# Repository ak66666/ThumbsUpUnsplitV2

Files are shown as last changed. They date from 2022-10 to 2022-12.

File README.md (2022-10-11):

# ThumbsUpUnsplitV2
Multilevel 44 Key Ergonomic Keyboard.
V2 puts the fourth row one level up.

The board uses Kailh Choc hot-swap switches.

//TODO Pictures to be replaced.

Main view
Three levels are visible






# Firmware
                                                               
The board uses Planck rev4 software with one pin replaced - it is needed for Cirque trackpad.
To make it work - modify \qmk_firmware\keyboards\planck\config.h, replace the pin definition with this one:

#define MATRIX_COL_PINS { D7, B4, D6, D4, F7, F6, F5, F4, C7, B0, F0, F1 }

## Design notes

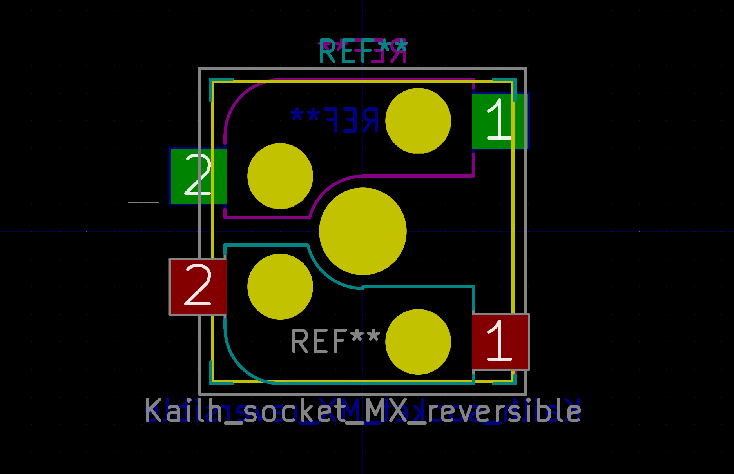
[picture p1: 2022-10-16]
keyswitches.pretty-master/images/Kailh_socket_MX_reversible_platemount.png

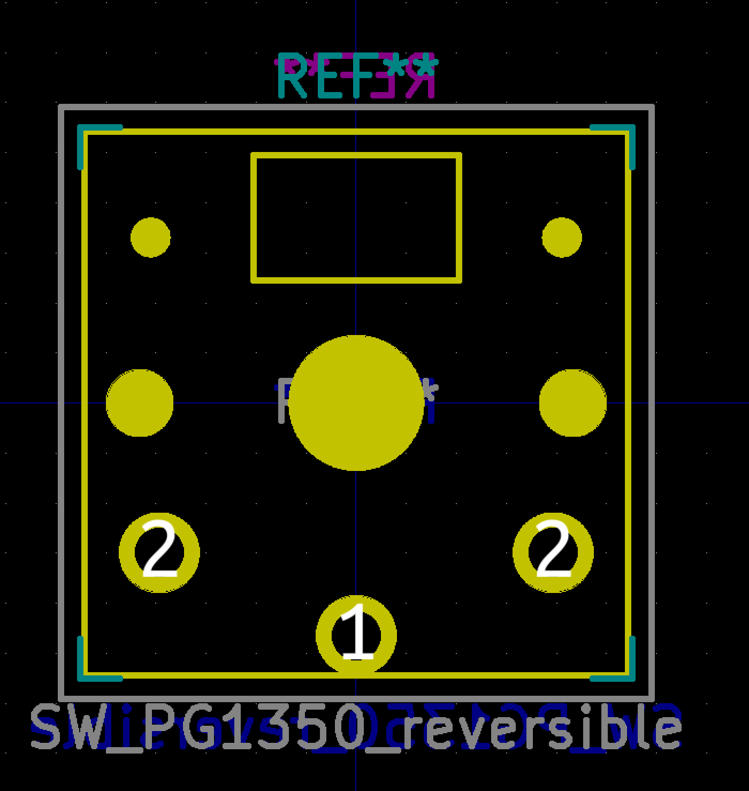
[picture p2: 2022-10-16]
keyswitches.pretty-master/images/SW_PG1350_reversible.png

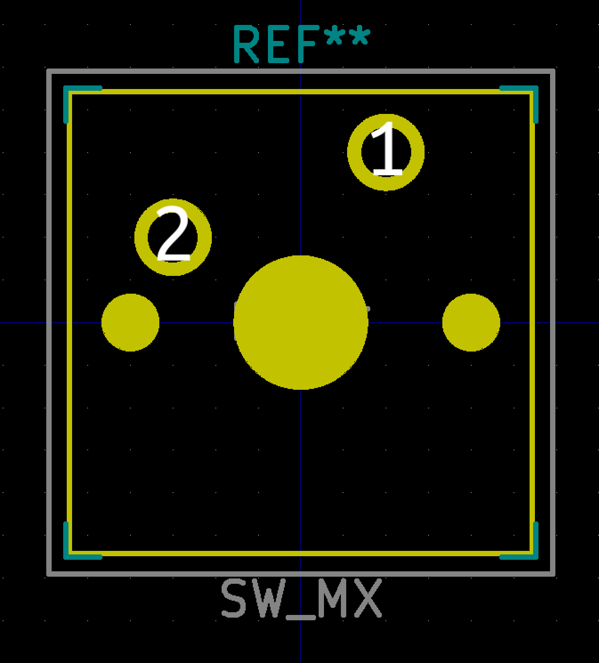
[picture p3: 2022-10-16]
keyswitches.pretty-master/images/SW_MX.png

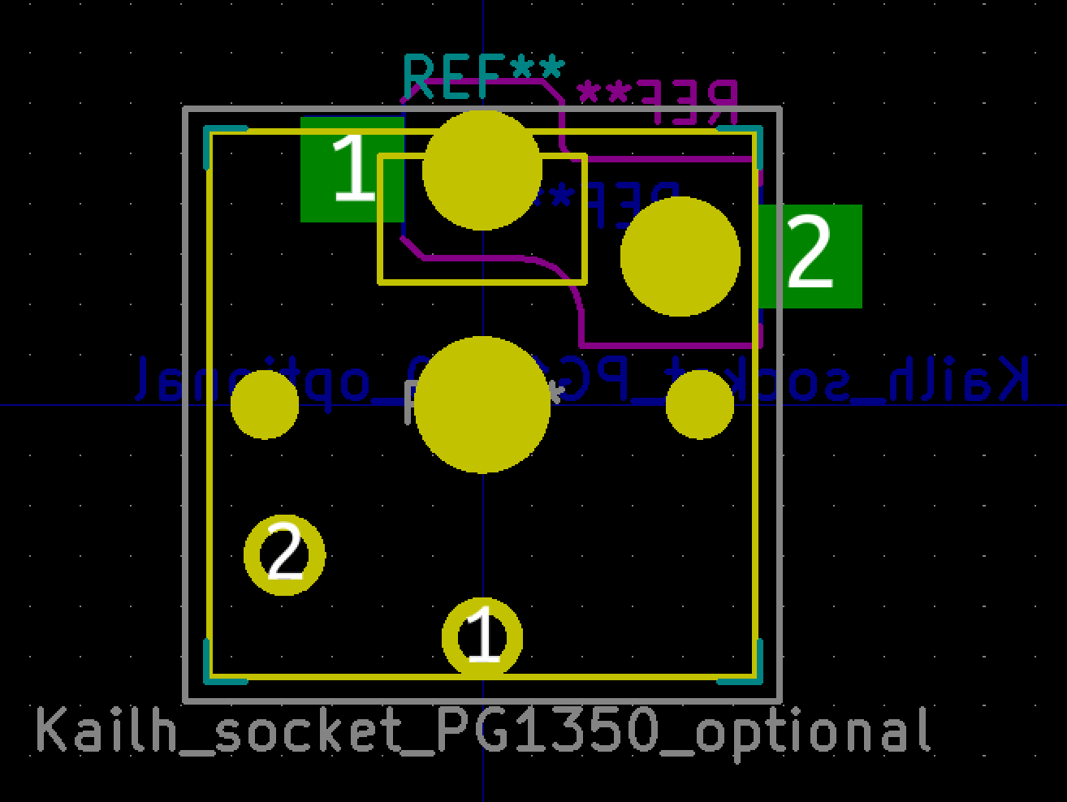
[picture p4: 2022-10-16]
keyswitches.pretty-master/images/Kailh_socket_PG1350_optional.png

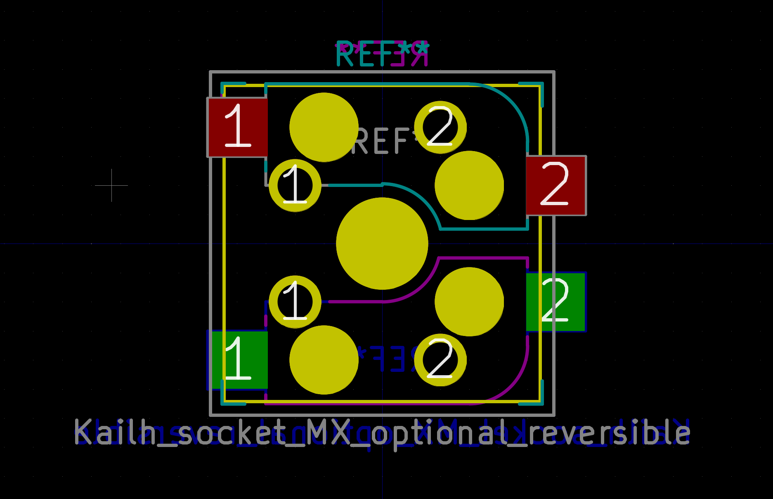
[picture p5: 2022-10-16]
keyswitches.pretty-master/images/Kailh_socket_MX_optional_reversible_platemount.png

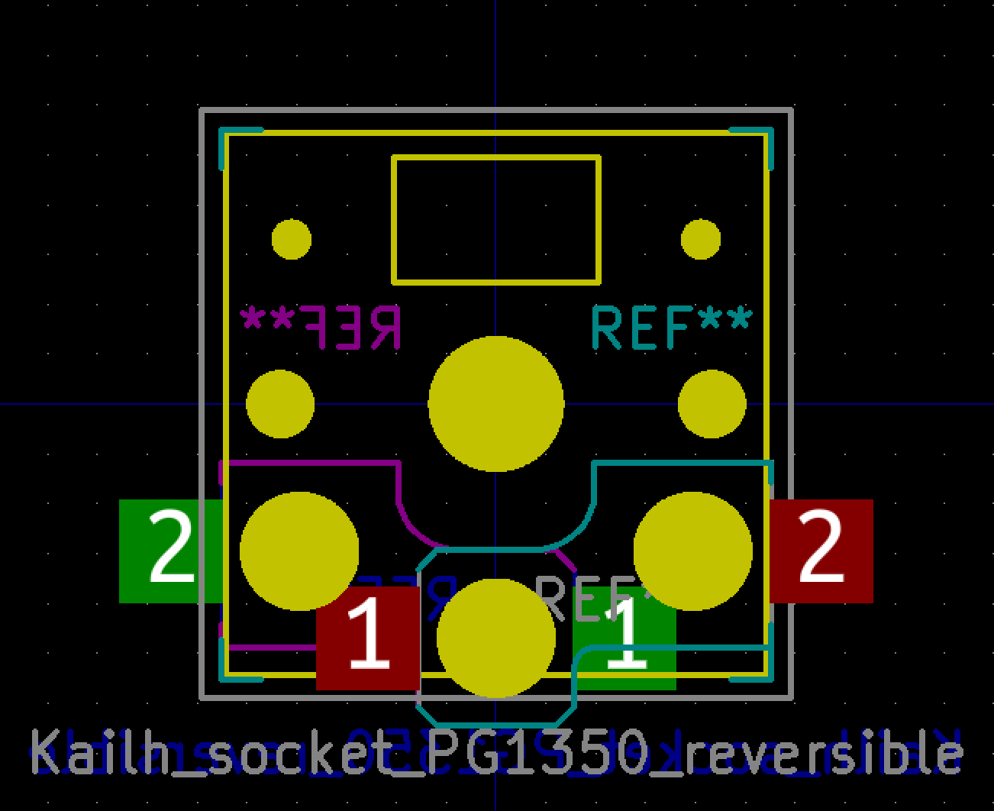
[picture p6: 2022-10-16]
keyswitches.pretty-master/images/Kailh_socket_PG1350_reversible.png

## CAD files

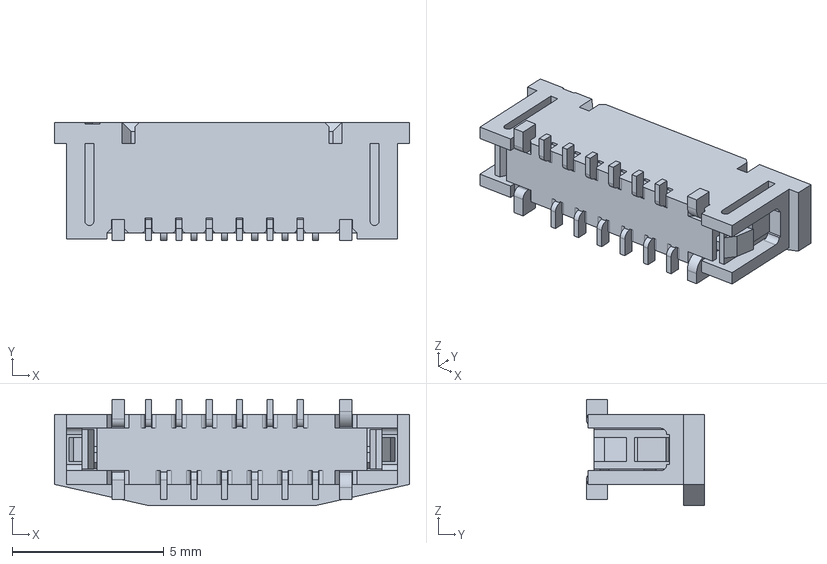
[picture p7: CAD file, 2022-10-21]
Molex 52559-1233/52559-1233/3D/52559-1233.stp
11.7 x 3.90 x 3.50 mm

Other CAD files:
Molex 52559-1233/52559-1233/Allegro/525591233.psm
Molex 52559-1233/52559-1233/DEHDL/52559_1233/chips/chips.prt

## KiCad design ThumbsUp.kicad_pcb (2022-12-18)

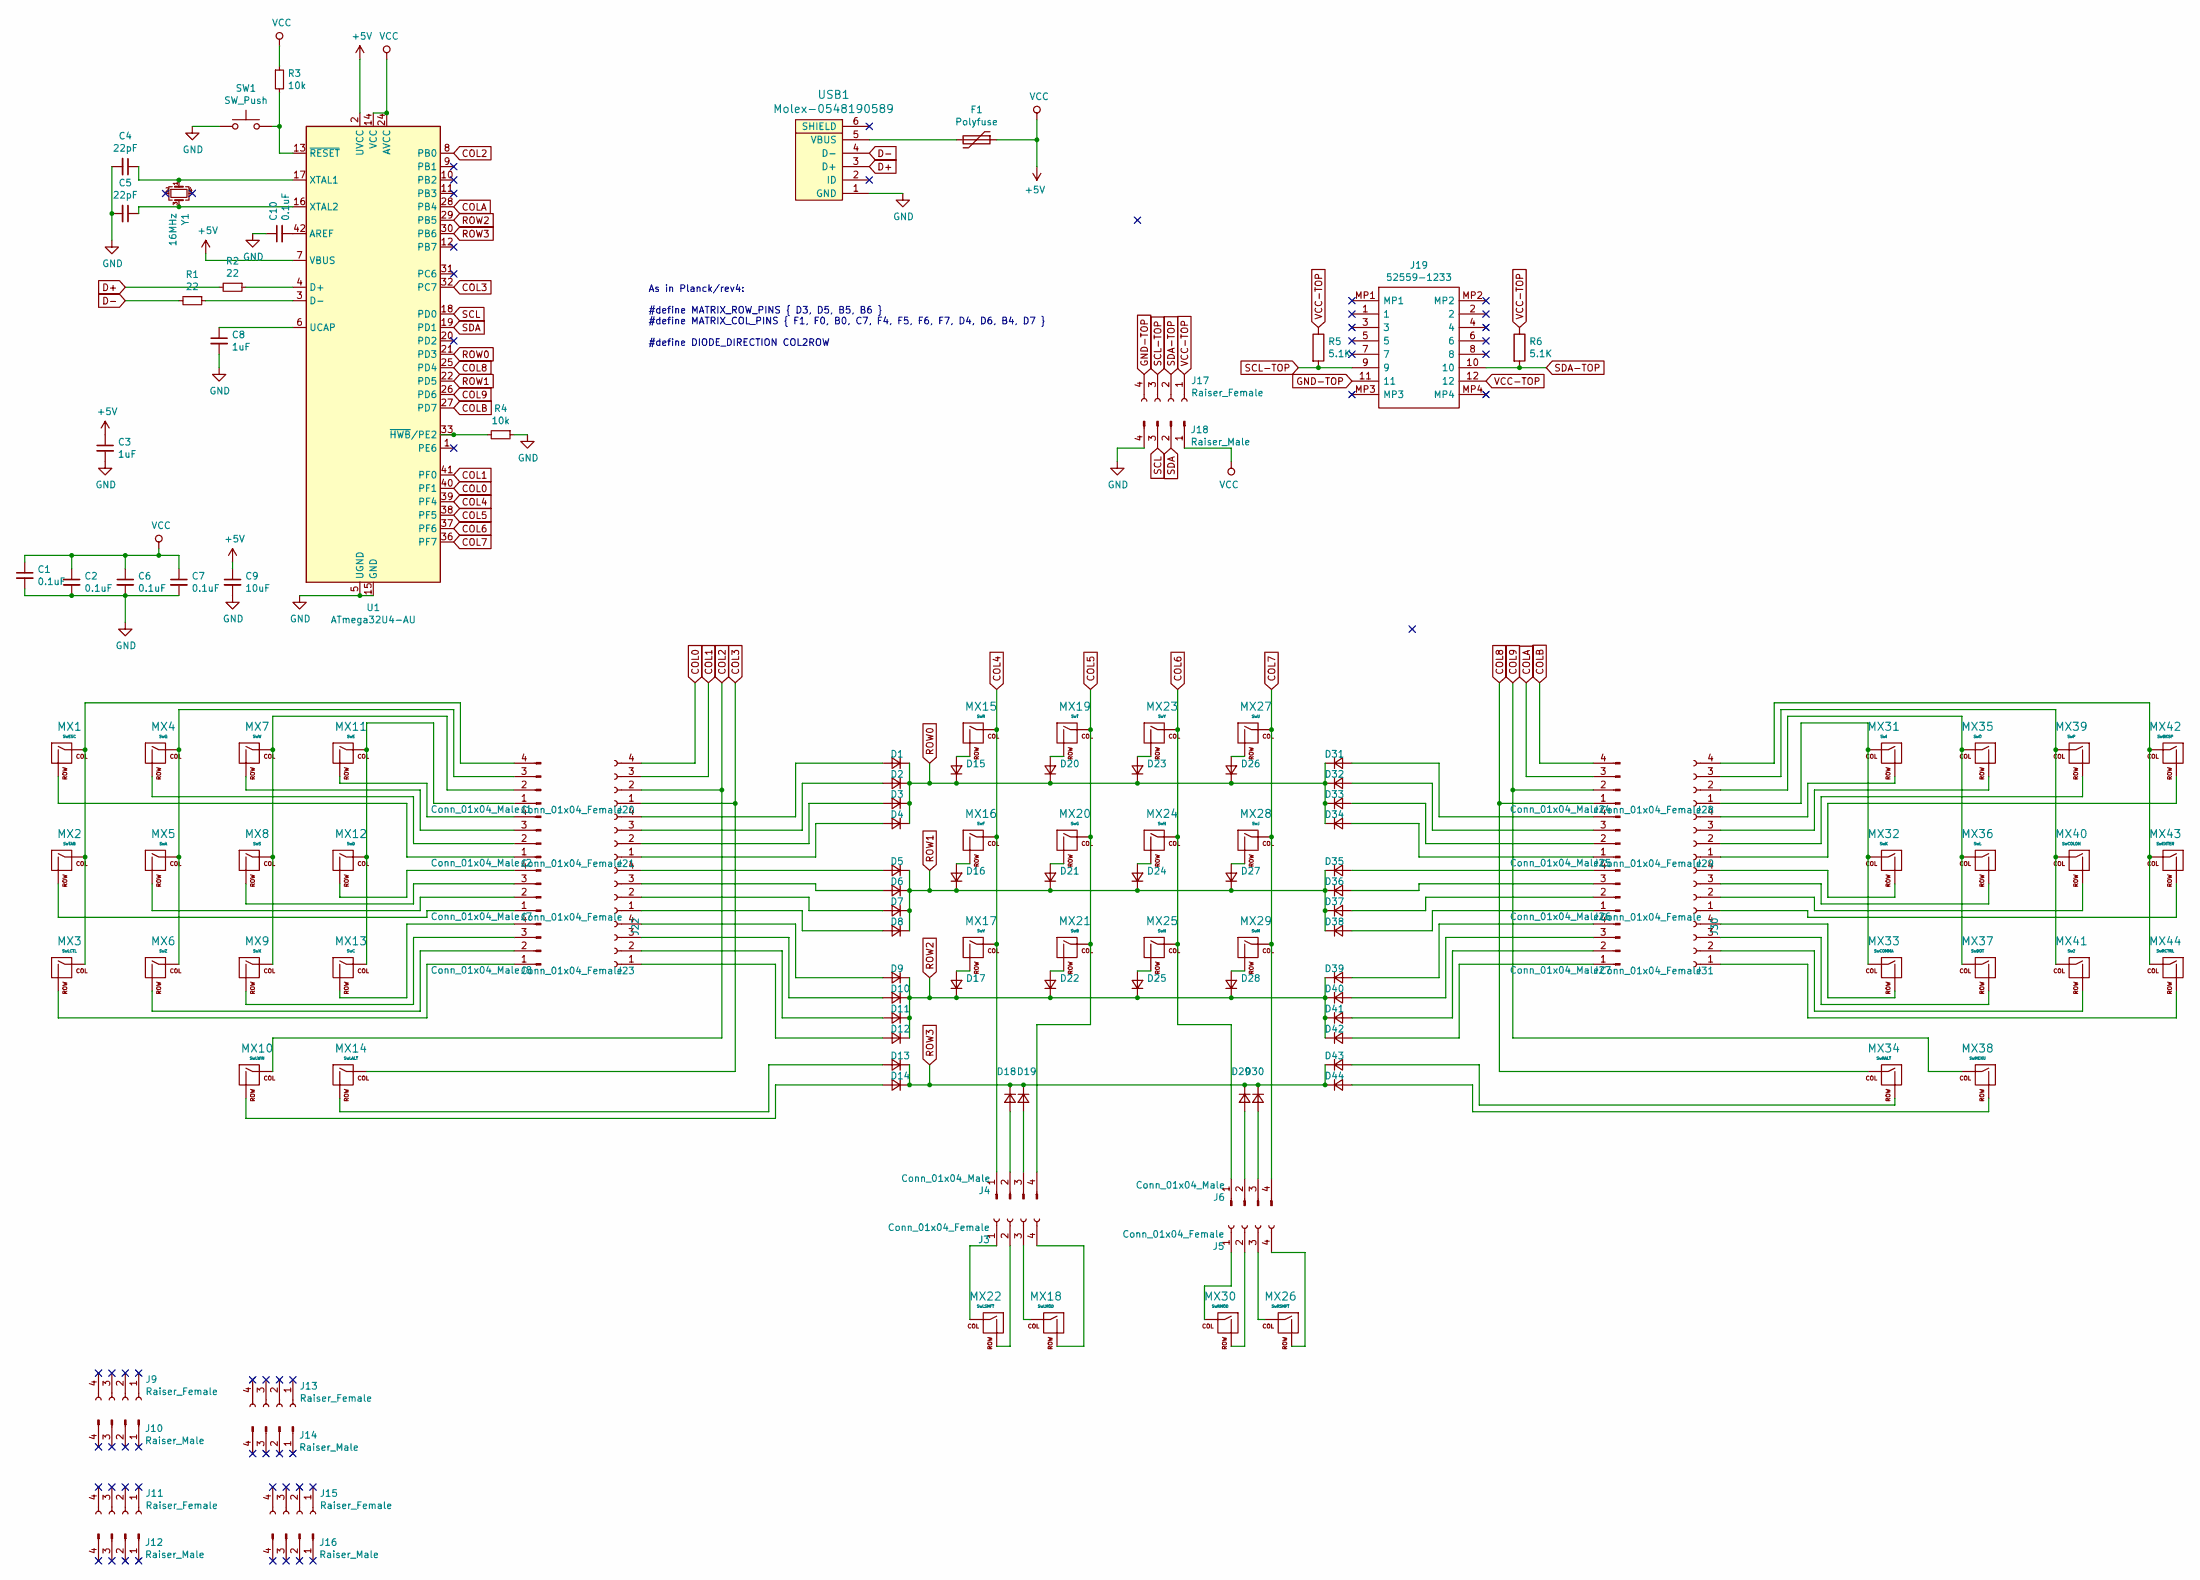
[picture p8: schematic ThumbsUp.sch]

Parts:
C1, C2, C6, C7, C10: 0.1uF; C_0805_2012Metric
C3, C8: 1uF; C_0805_2012Metric
C4, C5: 22pF; C_0805_2012Metric
C9: 10uF; C_0805_2012Metric
D1, D2, D3, D4, D5, D6, D7, D8, D9, D10, D11, D12, D13, D14, D15, D16, D17, D18, D19, D20, D21, D22, D23, D24, D25, D26, D27, D28, D29, D30, D31, D32, D33, D34, D35, D36, D37, D38, D39, D40, D41, D42, D43, D44: D_Small; D_SOD-123
F1: Polyfuse; Fuse_1206_3216Metric
J1, J2, J4, J6, J7, J8, J24, J25, J26, J27: Conn_01x04_Male; PinHeader_1x04_P2.54mm_Vertical
J3, J5, J20, J21, J22, J23, J28, J29, J30, J31: Conn_01x04_Female; PinSocket_1x04_P2.54mm_Vertical
J9, J11, J13, J15, J17: Raiser_Female; PinSocket_1x04_P2.54mm_Vertical
J10, J12, J14, J16, J18: Raiser_Male; PinHeader_1x04_P2.54mm_Vertical
J19: 52559-1233; 525591233; Mouser Part Number 538-52559-1233
MX1: SwESC; Kailh_socket_PG1350_optional
MX2: SwTAB; Kailh_socket_PG1350_optional
MX3: SwLCTL; Kailh_socket_PG1350_optional
MX4: SwQ; Kailh_socket_PG1350_optional
MX5: SwA; Kailh_socket_PG1350_optional
MX6: SwZ; Kailh_socket_PG1350_optional
MX7: SwW; Kailh_socket_PG1350_optional
MX8: SwS; Kailh_socket_PG1350_optional
MX9: SwX; Kailh_socket_PG1350_optional
MX10: SwLWIN; Kailh_socket_PG1350_optional
MX11: SwE; Kailh_socket_PG1350_optional
MX12: SwD; Kailh_socket_PG1350_optional
MX13: SwC; Kailh_socket_PG1350_optional
MX14: SwLALT; Kailh_socket_PG1350_optional
MX15: SwR; Kailh_socket_PG1350_optional
MX16: SwF; Kailh_socket_PG1350_optional
MX17: SwV; Kailh_socket_PG1350_optional
MX18: SwLMOD; Kailh_socket_PG1350_optional
MX19: SwT; Kailh_socket_PG1350_optional
MX20: SwG; Kailh_socket_PG1350_optional
MX21: SwB; Kailh_socket_PG1350_optional
MX22: SwLSHFT; Kailh_socket_PG1350_optional
MX23: SwY; Kailh_socket_PG1350_optional
MX24: SwH; Kailh_socket_PG1350_optional
MX25: SwN; Kailh_socket_PG1350_optional
MX26: SwRSHFT; Kailh_socket_PG1350_optional
MX27: SwU; Kailh_socket_PG1350_optional
MX28: SwJ; Kailh_socket_PG1350_optional
MX29: SwM; Kailh_socket_PG1350_optional
MX30: SwRMOD; Kailh_socket_PG1350_optional
MX31: SwI; Kailh_socket_PG1350_optional
MX32: SwK; Kailh_socket_PG1350_optional
MX33: SwCOMMA; Kailh_socket_PG1350_optional
MX34: SwRALT; Kailh_socket_PG1350_optional
MX35: SwO; Kailh_socket_PG1350_optional
MX36: SwL; Kailh_socket_PG1350_optional
MX37: SwDOT; Kailh_socket_PG1350_optional
MX38: SwMENU; Kailh_socket_PG1350_optional
MX39: SwP; Kailh_socket_PG1350_optional
MX40: SwCOLON; Kailh_socket_PG1350_optional
MX41: Sw?; Kailh_socket_PG1350_optional
MX42: SwBKSP; Kailh_socket_PG1350_optional
MX43: SwENTER; Kailh_socket_PG1350_optional
MX44: SwRCTRL; Kailh_socket_PG1350_optional
R1, R2: 22; R_0805_2012Metric
R3, R4: 10k; R_0805_2012Metric
R5, R6: 5.1K; R_0805_2012Metric
SW1: SW_Push; SKQG-1155865
U1: ATmega32U4-AU; TQFP-44_10x10mm_P0.8mm
USB1: Molex-0548190589
Y1: 16MHz; Crystal_SMD_3225-4Pin_3.2x2.5mm_HandSoldering

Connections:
+5V: C1.1, C2.1, C3.1, C6.1, C7.1, C9.1, F1.1, J18.1, R3.1, U1.2 (UVCC), U1.7 (VBUS), U1.14 (VCC), U1.24 (AVCC), U1.34 (VCC), U1.44 (AVCC)
COL0: J20.4, U1.40 (PF1)
COL1: J20.3, U1.41 (PF0)
COL2: J20.2, MX10.1 (COL), U1.8 (PB0)
COL3: J20.1, MX14.1 (COL), U1.32 (PC7)
COL4: J4.1, MX15.1 (COL), MX16.1 (COL), MX17.1 (COL), U1.39 (PF4)
COL5: J4.4, MX19.1 (COL), MX20.1 (COL), MX21.1 (COL), U1.38 (PF5)
COL6: J6.1, MX23.1 (COL), MX24.1 (COL), MX25.1 (COL), U1.37 (PF6)
COL7: J6.4, MX27.1 (COL), MX28.1 (COL), MX29.1 (COL), U1.36 (PF7)
COL8: J24.1, MX34.1 (COL), U1.25 (PD4)
COL9: J24.2, MX38.1 (COL), U1.26 (PD6)
COLA: J24.3, U1.28 (PB4)
COLB: J24.4, U1.27 (PD7)
D+: R2.2, USB1.3 (D+)
D-: R1.2, USB1.4 (D-)
GND: C1.2, C2.2, C3.2, C4.2, C5.2, C6.2, C7.2, C8.2, C9.2, C10.1, J18.4, R4.1, SW1.1, U1.5 (UGND), U1.15 (GND), U1.23 (GND), U1.35 (GND), U1.43 (GND), USB1.1 (GND)
GND-TOP: J17.4, J19.11
unnamed: C4.1, U1.17 (XTAL1), Y1.1
unnamed: C5.1, U1.16 (XTAL2), Y1.3
unnamed: C8.1, U1.6 (UCAP)
unnamed: C10.2, U1.42 (AREF)
unnamed: D1.2 (A), J21.4
unnamed: D2.2 (A), J21.3
unnamed: D3.2 (A), J21.2
unnamed: D4.2 (A), J21.1
unnamed: D5.2 (A), J22.4
unnamed: D6.2 (A), J22.3
unnamed: D7.2 (A), J22.2
unnamed: D8.2 (A), J22.1
unnamed: D9.2 (A), J23.4
unnamed: D10.2 (A), J23.3
unnamed: D11.2 (A), J23.2
unnamed: D12.2 (A), J23.1
unnamed: D13.2 (A), MX14.2 (ROW)
unnamed: D14.2 (A), MX10.2 (ROW)
unnamed: D15.2 (A), MX15.2 (ROW)
unnamed: D16.2 (A), MX16.2 (ROW)
unnamed: D17.2 (A), MX17.2 (ROW)
unnamed: D18.2 (A), J4.2
unnamed: D19.2 (A), J4.3
unnamed: D20.2 (A), MX19.2 (ROW)
unnamed: D21.2 (A), MX20.2 (ROW)
unnamed: D22.2 (A), MX21.2 (ROW)
unnamed: D23.2 (A), MX23.2 (ROW)
unnamed: D24.2 (A), MX24.2 (ROW)
unnamed: D25.2 (A), MX25.2 (ROW)
unnamed: D26.2 (A), MX27.2 (ROW)
unnamed: D27.2 (A), MX28.2 (ROW)
unnamed: D28.2 (A), MX29.2 (ROW)
unnamed: D29.2 (A), J6.2
unnamed: D30.2 (A), J6.3
unnamed: D31.2 (A), J25.4
unnamed: D32.2 (A), J25.3
unnamed: D33.2 (A), J25.2
unnamed: D34.2 (A), J25.1
unnamed: D35.2 (A), J26.4
unnamed: D36.2 (A), J26.3
unnamed: D37.2 (A), J26.2
unnamed: D38.2 (A), J26.1
unnamed: D39.2 (A), J27.4
unnamed: D40.2 (A), J27.3
unnamed: D41.2 (A), J27.2
unnamed: D42.2 (A), J27.1
unnamed: D43.2 (A), MX34.2 (ROW)
unnamed: D44.2 (A), MX38.2 (ROW)
unnamed: F1.2, USB1.5 (VBUS)
unnamed: J1.1, MX11.1 (COL), MX12.1 (COL), MX13.1 (COL)
unnamed: J1.2, MX7.1 (COL), MX8.1 (COL), MX9.1 (COL)
unnamed: J1.3, MX4.1 (COL), MX5.1 (COL), MX6.1 (COL)
unnamed: J1.4, MX1.1 (COL), MX2.1 (COL), MX3.1 (COL)
unnamed: J2.1, MX1.2 (ROW)
unnamed: J2.2, MX4.2 (ROW)
unnamed: J2.3, MX7.2 (ROW)
unnamed: J2.4, MX11.2 (ROW)
unnamed: J3.1, MX22.1 (COL)
unnamed: J3.2, MX22.2 (ROW)
unnamed: J3.3, MX18.1 (COL)
unnamed: J3.4, MX18.2 (ROW)
unnamed: J5.1, MX30.1 (COL)
unnamed: J5.2, MX30.2 (ROW)
unnamed: J5.3, MX26.1 (COL)
unnamed: J5.4, MX26.2 (ROW)
unnamed: J7.1, MX2.2 (ROW)
unnamed: J7.2, MX5.2 (ROW)
unnamed: J7.3, MX8.2 (ROW)
unnamed: J7.4, MX12.2 (ROW)
unnamed: J8.1, MX3.2 (ROW)
unnamed: J8.2, MX6.2 (ROW)
unnamed: J8.3, MX9.2 (ROW)
unnamed: J8.4, MX13.2 (ROW)
unnamed: J28.1, MX31.1 (COL), MX32.1 (COL), MX33.1 (COL)
unnamed: J28.2, MX35.1 (COL), MX36.1 (COL), MX37.1 (COL)
unnamed: J28.3, MX39.1 (COL), MX40.1 (COL), MX41.1 (COL)
unnamed: J28.4, MX42.1 (COL), MX43.1 (COL), MX44.1 (COL)
unnamed: J29.1, MX42.2 (ROW)
unnamed: J29.2, MX39.2 (ROW)
unnamed: J29.3, MX35.2 (ROW)
unnamed: J29.4, MX31.2 (ROW)
unnamed: J30.1, MX43.2 (ROW)
unnamed: J30.2, MX40.2 (ROW)
unnamed: J30.3, MX36.2 (ROW)
unnamed: J30.4, MX32.2 (ROW)
unnamed: J31.1, MX44.2 (ROW)
unnamed: J31.2, MX41.2 (ROW)
unnamed: J31.3, MX37.2 (ROW)
unnamed: J31.4, MX33.2 (ROW)
unnamed: R1.1, U1.3 (D-)
unnamed: R2.1, U1.4 (D+)
unnamed: R3.2, SW1.2, U1.13 (~RESET)
unnamed: R4.2, U1.33 (~HWB~/PE2)
ROW0: D1.1 (K), D2.1 (K), D3.1 (K), D4.1 (K), D15.1 (K), D20.1 (K), D23.1 (K), D26.1 (K), D31.1 (K), D32.1 (K), D33.1 (K), D34.1 (K), U1.21 (PD3)
ROW1: D5.1 (K), D6.1 (K), D7.1 (K), D8.1 (K), D16.1 (K), D21.1 (K), D24.1 (K), D27.1 (K), D35.1 (K), D36.1 (K), D37.1 (K), D38.1 (K), U1.22 (PD5)
ROW2: D9.1 (K), D10.1 (K), D11.1 (K), D12.1 (K), D17.1 (K), D22.1 (K), D25.1 (K), D28.1 (K), D39.1 (K), D40.1 (K), D41.1 (K), D42.1 (K), U1.29 (PB5)
ROW3: D13.1 (K), D14.1 (K), D18.1 (K), D19.1 (K), D29.1 (K), D30.1 (K), D43.1 (K), D44.1 (K), U1.30 (PB6)
SCL: J18.3, U1.18 (PD0)
SCL-TOP: J17.3, J19.9, R5.2
SDA: J18.2, U1.19 (PD1)
SDA-TOP: J17.2, J19.10, R6.2
VCC-TOP: J17.1, J19.12, R5.1, R6.1

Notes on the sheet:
As in Planck/rev4: #define MATRIX_ROW_PINS { D3, D5, B5, B6 } #define MATRIX_COL_PINS { F1, F0, B0, C7, F4, F5, F6, F7, D4, D6, B4, D7 } #define DIODE_DIRECTION COL2ROW

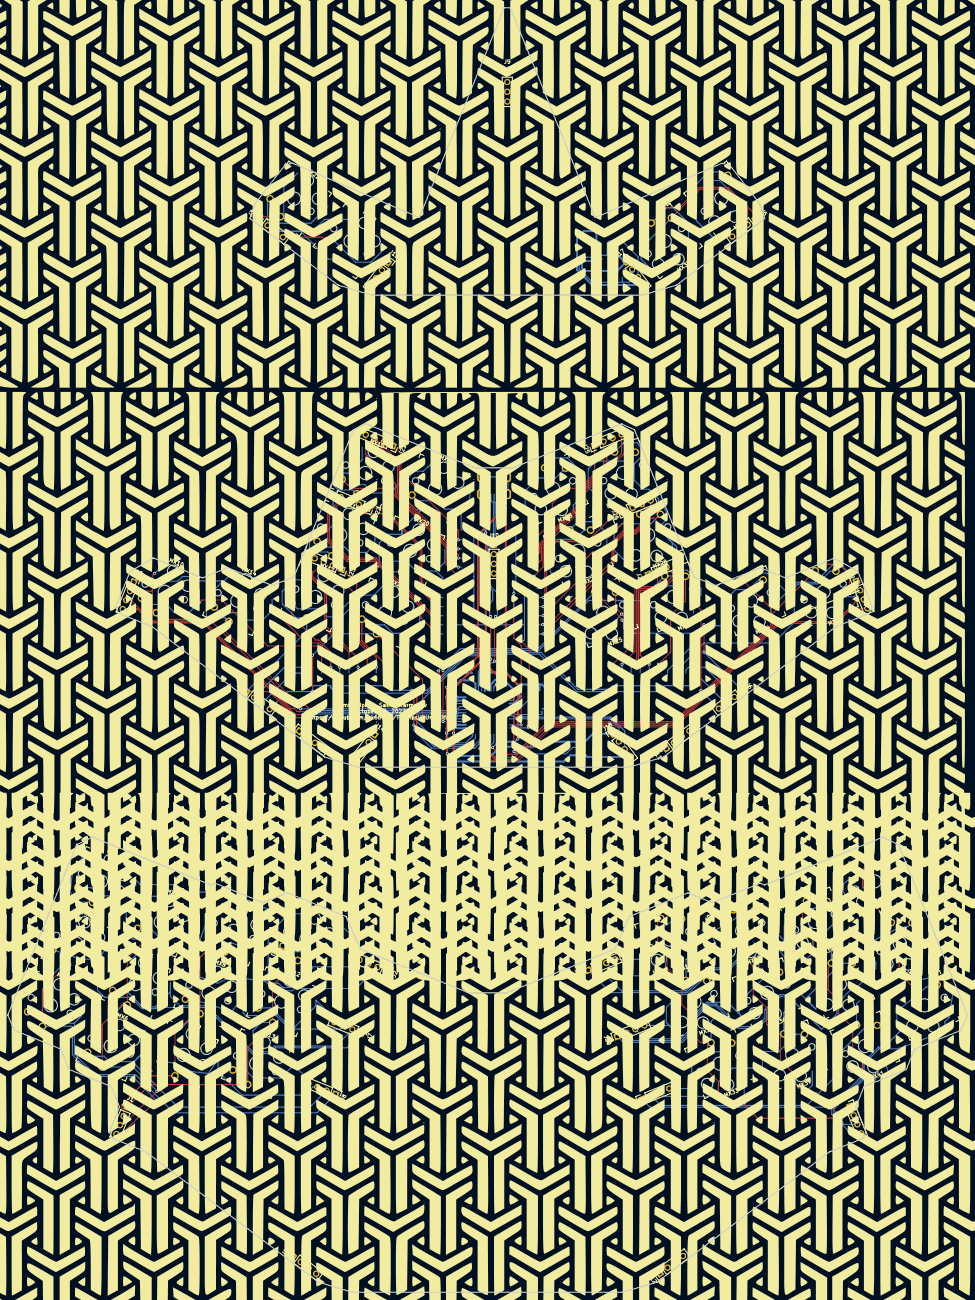
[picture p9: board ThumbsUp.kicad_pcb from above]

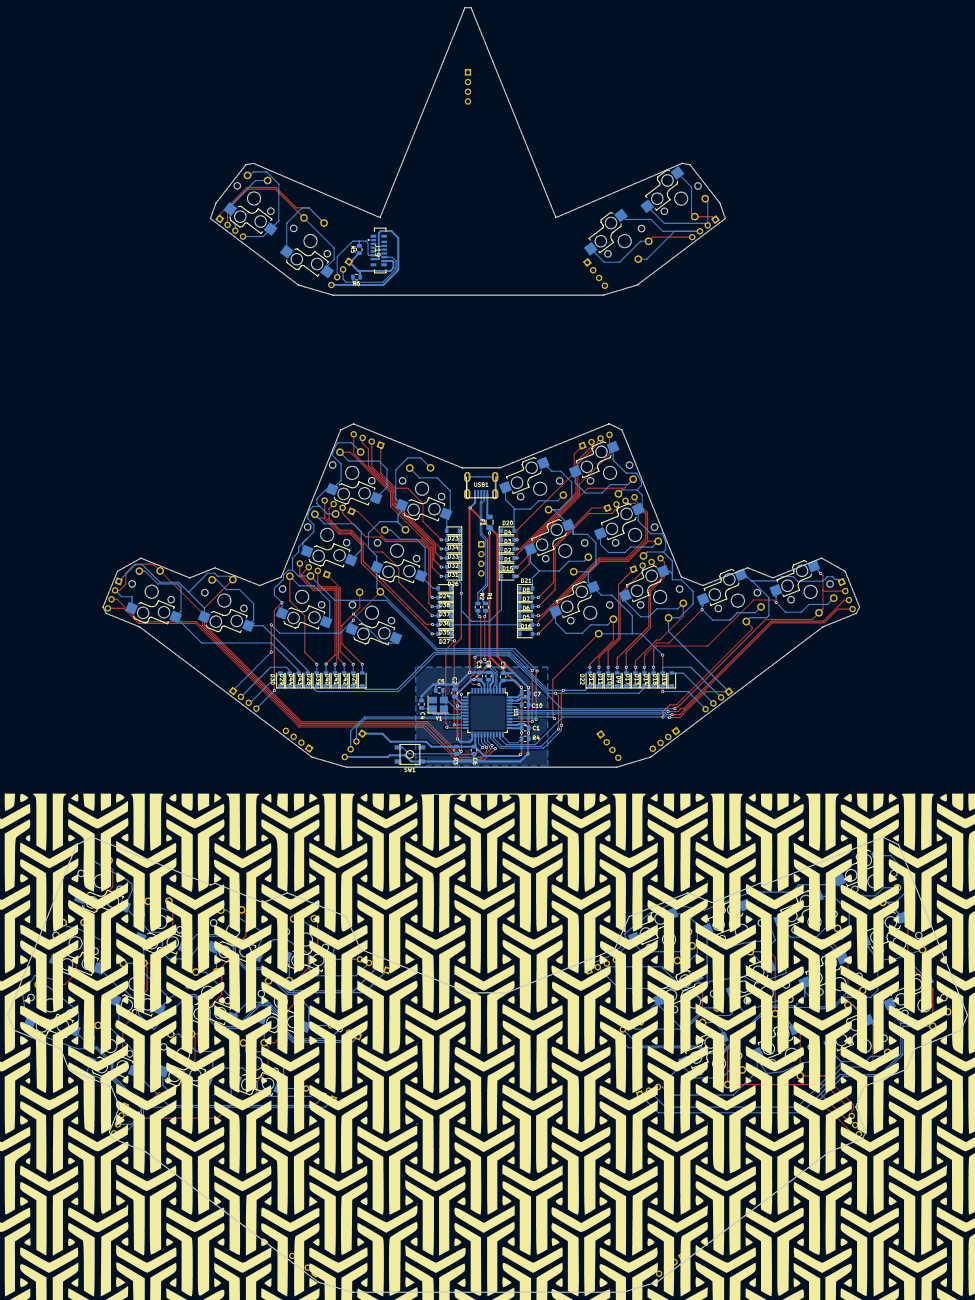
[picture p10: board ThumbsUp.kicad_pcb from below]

Board: 2 copper layers, 251.1 x 336.1 mm, 140 parts (66 on the bottom side), 119 nets.

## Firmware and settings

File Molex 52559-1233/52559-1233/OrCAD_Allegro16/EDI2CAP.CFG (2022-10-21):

;>------- Configuration parameters: -------<
;>------Check EDIF2CAP.PDF for details ----<

[OrCAD Writer]

SuppressWarnings = 0	
ConvertOnlyLibs = 0
UnitMeasurement = default
PinToPin = 0
Grid = 0
EnableOffgridObjects = 0
GenerateIniFile = 1
OrcadConventions = 1
UseDesignatorsForPackaging = 1
DesignatorsEndOnLetters = 0
DesignatorsSameInHierarchy = 1
GeneratePinNumbers = 0
GeneratePortSymbols = 1
GenerateOffPageConnectors = 0
GenerationVisible = 1
CaptureLibsWithUserPackages = ""
SystemNetNamePrefix = ""
BackgroundTextScale = 0.8
DefaultNetNameScale = 0.3
StandardPageSize = 0
EliminatePageText = 0
SmashTitleBlock = 0
PinDisplayStyle = orcad
TopView = ""
ComponentsMode = 0
ReplacePartWithNoPinsWithTitleBlock = 0
ChangeBusBaseThatEndsOnDigit = 0
ProcessBackAnnotation = 1

[Mapper]

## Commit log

2022-10-11 Initial version
    [ThumbsUp.kicad_pcb, ThumbsUp.sch]
2022-10-16 Added the trackpad socket
2022-10-21 Started the layout
    [52559-1233.stp, 525591233.psm, EDI2CAP.CFG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]
2022-10-22 Working on the layout
    [ThumbsUp.kicad_pcb, ThumbsUp.sch]
2022-10-23 Split the boards
    [ThumbsUp.kicad_pcb]
2022-10-23 End of the day resuls
    [ThumbsUp.kicad_pcb]
2022-10-30 Laid some tracks
    [ThumbsUp.kicad_pcb]
2022-10-30 Tracks are almost finished
    [ThumbsUp.kicad_pcb]
2022-10-30 Removed the exta footprints
    [ThumbsUp.kicad_pcb]
2022-11-03 Somewhat completed the development
    [ThumbsUp.kicad_pcb, ThumbsUp.sch]
2022-11-10 Moved the tracks from under MCU
    [ThumbsUp-B_Cu.gbl, ThumbsUp-B_Cu.gbr, ThumbsUp-B_Mask.gbr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]
2022-11-11 Redrew the middle board
    [ThumbsUp.kicad_pcb, ThumbsUp.sch]
2022-11-23 Swapped space and shift keys
    [ThumbsUp.kicad_pcb, ThumbsUp.sch]
2022-11-24 Somewhat complete
    [ThumbsUp-B_Cu.gbr, ThumbsUp-B_Mask.gbr, ThumbsUp-B_Paste.gbr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]
2022-12-05 Moved the touchpad connector
    [ThumbsUp.kicad_pcb]
2022-12-12 Regenerated Gerber for the top layer
    [ThumbsUp-B_Cu.gbr, ThumbsUp-B_Mask.gbr, ThumbsUp-B_Paste.gbr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]
2022-12-18 Added pullup resistors for trackpad, re-produced the gerbers
    [ThumbsUp-B_Cu.gbr, ThumbsUp-B_Mask.gbr, ThumbsUp-B_Paste.gbr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]
